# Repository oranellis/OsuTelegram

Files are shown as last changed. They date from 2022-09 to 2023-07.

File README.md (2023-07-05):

# OsuTelegram
Introducing a contact based keypad designed to make tapping in time on two key rhythm games (osu!) faster, tigher timed and requiring less force leading to faster streaming, better accuracy and less fatigue when playing. The keypad requires an RP2040-Zero Microcontroller (found cheaply online), 2 5mmx3mm magnets, 2 49E Linear Hall effect sensors, 4 bearings (8x4x3mm), two keyswitch springs (choose force based on preference however a lighter spring e.g. 35-40g is recommended for less fatigue), and access to a 3D printer.

To construct the keypad, print the .stl files in the `mdl` folder. Glue the hall effect sensors in the gaps on the base with the rounded section facing into the slot. Wire up the hall sensors to GND, 5V and the two analogue inputs shown on the wiring diagram. Slot the bearings onto the keyswitch ends and push fit the magnets into the holes on the bottom. Glue a strip of 1mm thick foam over the hall sensor pad. Slot the keyswitch and bearings into the base and slot the springs into the base and switches. Glue the top peice onto the base, encasing the bearings and switches. Plug the RP2040-Zero into a computer running linux and run the flashing script, alternatively compile the project and flash the RP2040-Zero yourself if you are able.

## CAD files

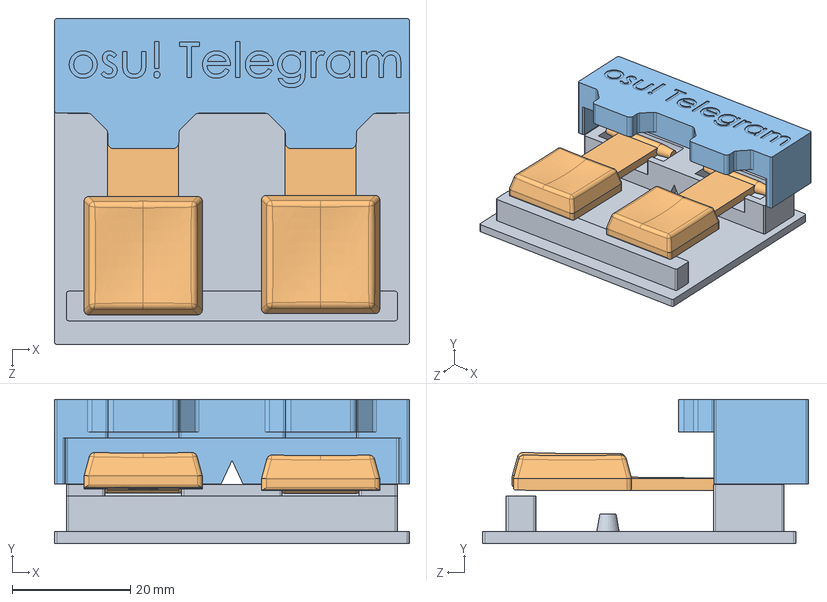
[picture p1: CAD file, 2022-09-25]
mdl/keypad assembly.SLDASM
60.0 x 24.3 x 55.1 mm
case bottom
key x 2
case top

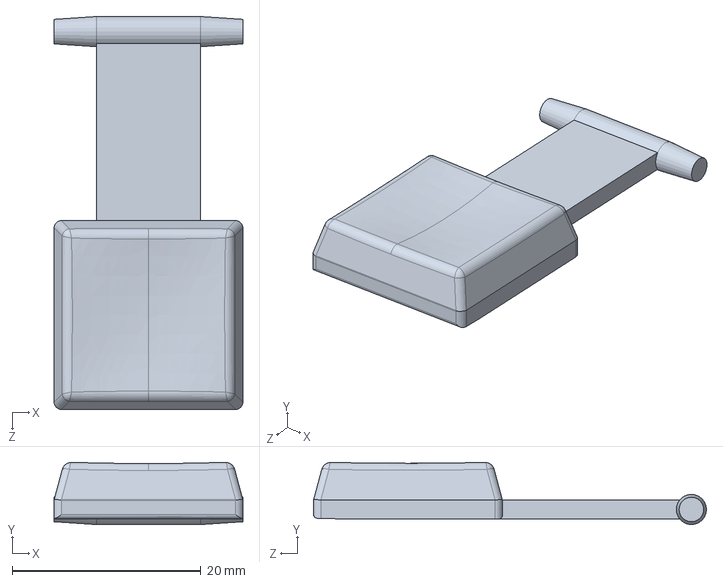
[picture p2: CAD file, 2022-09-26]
mdl/key.SLDPRT
20.0 x 6.58 x 41.6 mm

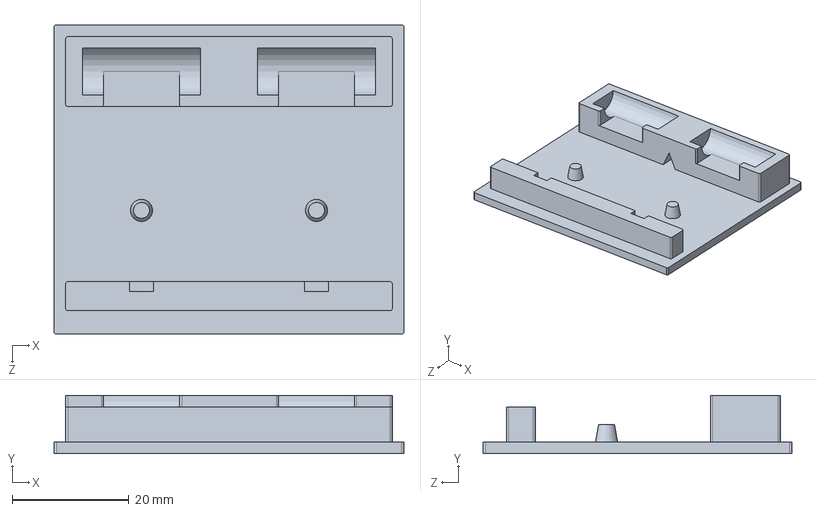
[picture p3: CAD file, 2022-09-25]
mdl/case bottom.SLDPRT
60.0 x 10.0 x 53.0 mm

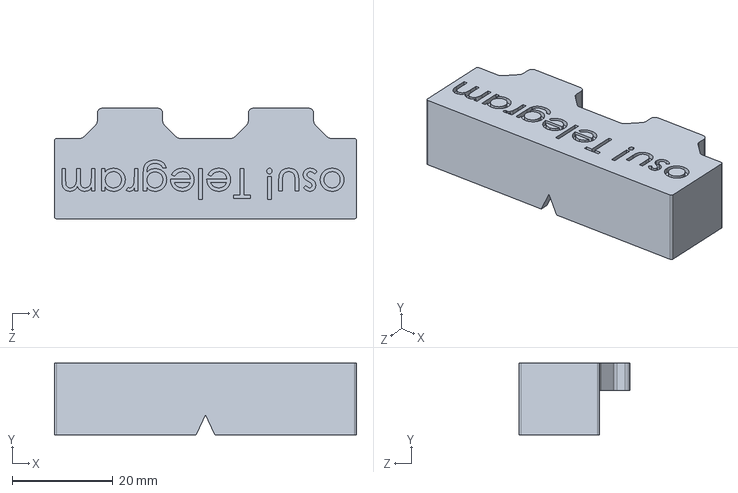
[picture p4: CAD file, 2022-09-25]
mdl/case top.SLDPRT
60.0 x 14.3 x 22.0 mm

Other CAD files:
mdl/case bottom.STL
mdl/case top.STL

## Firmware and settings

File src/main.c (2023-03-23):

/* 
 * The MIT License (MIT)
 *
 * Copyright (c) 2019 Ha Thach (tinyusb.org)
 *
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
 */
#include <stdlib.h>
#include <stdio.h>
#include <string.h>

#include "bsp/board.h"
#include "tusb.h"
#include "hardware/adc.h"
#include "hardware/gpio.h"
#include "hardware/sync.h"
#include "hardware/structs/ioqspi.h"
#include "hardware/structs/sio.h"

#include "usb_descriptors.h"
#include "thing.h"

#define ADC0 26
#define ADC1 27

//--------------------------------------------------------------------+
// MACRO CONSTANT TYPEDEF PROTYPES
//--------------------------------------------------------------------+

/* Blink pattern
 * - 250 ms  : device not mounted
 * - 1000 ms : device mounted
 * - 2500 ms : device is suspended
 */


enum  {
  BLINK_NOT_MOUNTED = 250,
  BLINK_MOUNTED = 1000,
  BLINK_SUSPENDED = 2500,
};

bool z_hold = false;
bool x_hold = false;
int X_TRIG = 1960;
int X_RELEASE = 2110;
int Z_TRIG = 2230;
int Z_RELEASE = 2430;
uint16_t Z_UNPRESSED = 0;
uint16_t X_UNPRESSED = 0;


static uint32_t blink_interval_ms = BLINK_NOT_MOUNTED;

void led_blinking_task(void);
void hid_task(void);

/*------------- MAIN -------------*/
int main(void)
{
    board_init();

    adc_init();
    adc_gpio_init(ADC0);
    adc_gpio_init(ADC1);
    tusb_init();

    sleep_ms(500);
    adc_select_input(0);
    uint16_t Z_UNPRESSED = adc_read();
    adc_select_input(1);
    uint16_t X_UNPRESSED = adc_read();
    board_led_write(true);
    while (1)
    {
    tud_task(); // tinyusb device task
    // led_blinking_task();
    hid_task();
}

return 0;
}

//--------------------------------------------------------------------+
// Device callbacks
//--------------------------------------------------------------------+

// Invoked when device is mounted
void tud_mount_cb(void)
{
  blink_interval_ms = BLINK_MOUNTED;
}

// Invoked when device is unmounted
void tud_umount_cb(void)
{
  blink_interval_ms = BLINK_NOT_MOUNTED;
}

// Invoked when usb bus is suspended
// remote_wakeup_en : if host allow us  to perform remote wakeup
// Within 7ms, device must draw an average of current less than 2.5 mA from bus
void tud_suspend_cb(bool remote_wakeup_en)
{
  (void) remote_wakeup_en;
  blink_interval_ms = BLINK_SUSPENDED;
}

// Invoked when usb bus is resumed
void tud_resume_cb(void)
{
  blink_interval_ms = BLINK_MOUNTED;
}

//--------------------------------------------------------------------+
// USB HID
//--------------------------------------------------------------------+

static void send_hid_report(uint8_t report_id, bool x_hold, bool z_hold)
{
  // skip if hid is not ready yet
  if ( !tud_hid_ready() ) return;

  switch(report_id)
  {
    case REPORT_ID_KEYBOARD:
    {
      // use to avoid send multiple consecutive zero report for keyboard
      static bool has_keyboard_key = false;

      if ( x_hold || z_hold )
      {
        uint8_t keycode[6] = { 0 };
        keycode[0] = HID_KEY_X * x_hold;
        keycode[1] = HID_KEY_Z * z_hold;

        tud_hid_keyboard_report(REPORT_ID_KEYBOARD, 0, keycode);
        has_keyboard_key = true;
      }else
      {
        // send empty key report if previously has key pressed
        if (has_keyboard_key) tud_hid_keyboard_report(REPORT_ID_KEYBOARD, 0, NULL);
        has_keyboard_key = false;
      }
    }
    break;

    case REPORT_ID_MOUSE:
    {
      int8_t const delta = 0;

      // no button, right + down, no scroll, no pan
      tud_hid_mouse_report(REPORT_ID_MOUSE, 0x00, delta, delta, 0, 0);
    }
    break;

    case REPORT_ID_CONSUMER_CONTROL:
    {
      // use to avoid send multiple consecutive zero report
      static bool has_consumer_key = false;

      if ( false )
      {
        // volume down
        uint16_t volume_down = HID_USAGE_CONSUMER_VOLUME_DECREMENT;
        tud_hid_report(REPORT_ID_CONSUMER_CONTROL, &volume_down, 2);
        has_consumer_key = true;
      }else
      {
        // send empty key report (release key) if previously has key pressed
        uint16_t empty_key = 0;
        if (has_consumer_key) tud_hid_report(REPORT_ID_CONSUMER_CONTROL, &empty_key, 2);
        has_consumer_key = false;
      }
    }
    break;

    case REPORT_ID_GAMEPAD:
    {
      // use to avoid send multiple consecutive zero report for keyboard
      static bool has_gamepad_key = false;

      hid_gamepad_report_t report =
      {
        .x   = 0, .y = 0, .z = 0, .rz = 0, .rx = 0, .ry = 0,
        .hat = 0, .buttons = 0
      };

      if ( false )
      {
        report.hat = GAMEPAD_HAT_UP;
        report.buttons = GAMEPAD_BUTTON_A;
        tud_hid_report(REPORT_ID_GAMEPAD, &report, sizeof(report));

        has_gamepad_key = true;
      }else
      {
        report.hat = GAMEPAD_HAT_CENTERED;
        report.buttons = 0;
        if (has_gamepad_key) tud_hid_report(REPORT_ID_GAMEPAD, &report, sizeof(report));
        has_gamepad_key = false;
      }
    }
    break;

    default: break;
  }
}

// Every 10ms, we will sent 1 report for each HID profile (keyboard, mouse etc ..)
// tud_hid_report_complete_cb() is used to send the next report after previous one is complete
void hid_task(void)
{
  // Poll every 10ms
  const uint32_t interval_ms = 1;
  static uint32_t start_ms = 0;

  if ( board_millis() - start_ms < interval_ms) return; // not enough time
  start_ms += interval_ms;

    adc_select_input(0);
    uint16_t result_z = adc_read();
    adc_select_input(1);
    uint16_t result_x = adc_read();

    if (get_bootsel_buttony()) {
        // X_TRIG = X_UNPRESSED-(0.8*(X_UNPRESSED-result_x));
        // Z_TRIG = Z_UNPRESSED-(0.8*(Z_UNPRESSED-result_z));
        // X_RELEASE = X_UNPRESSED-(0.6*(X_UNPRESSED-result_x));
        // Z_RELEASE = Z_UNPRESSED-(0.6*(Z_UNPRESSED-result_z));
        X_TRIG = result_x*1.1;
        Z_TRIG = result_z*1.1;
        X_RELEASE = result_x*1.2;
        Z_RELEASE = result_z*1.2;
    }

    if (!z_hold && result_z < Z_TRIG) {
        z_hold = true;
    }
    if (z_hold && result_z > Z_RELEASE) {
        z_hold = false;
    }

    if (!x_hold && result_x < X_TRIG) {
        x_hold = true;
    }
    if (x_hold && result_x > X_RELEASE) {
        x_hold = false;
    }

  // Remote wakeup
  if ( tud_suspended() && (x_hold || z_hold) )
  {
    // Wake up host if we are in suspend mode
    // and REMOTE_WAKEUP feature is enabled by host
    tud_remote_wakeup();
  }else
  {
    // Send the 1st of report chain, the rest will be sent by tud_hid_report_complete_cb()
    send_hid_report(REPORT_ID_KEYBOARD, x_hold, z_hold);
  }
}

// Invoked when sent REPORT successfully to host
// Application can use this to send the next report
// Note: For composite reports, report[0] is report ID
void tud_hid_report_complete_cb(uint8_t instance, uint8_t const* report, uint8_t len)
{
  (void) instance;
  (void) len;

  uint8_t next_report_id = report[0] + 1;

  if (next_report_id < REPORT_ID_COUNT)
  {
    send_hid_report(next_report_id, x_hold, z_hold);
  }
}

// Invoked when received GET_REPORT control request
// Application must fill buffer report's content and return its length.
// Return zero will cause the stack to STALL request
uint16_t tud_hid_get_report_cb(uint8_t instance, uint8_t report_id, hid_report_type_t report_type, uint8_t* buffer, uint16_t reqlen)
{
  // TODO not Implemented
  (void) instance;
  (void) report_id;
  (void) report_type;
  (void) buffer;
  (void) reqlen;

  return 0;
}

// Invoked when received SET_REPORT control request or
// received data on OUT endpoint ( Report ID = 0, Type = 0 )
void tud_hid_set_report_cb(uint8_t instance, uint8_t report_id, hid_report_type_t report_type, uint8_t const* buffer, uint16_t bufsize)
{
  (void) instance;

  if (report_type == HID_REPORT_TYPE_OUTPUT)
  {
    // Set keyboard LED e.g Capslock, Numlock etc...
    if (report_id == REPORT_ID_KEYBOARD)
    {
      // bufsize should be (at least) 1
      if ( bufsize < 1 ) return;

    }
  }
}

//--------------------------------------------------------------------+
// BLINKING TASK
//--------------------------------------------------------------------+
void led_blinking_task(void)
{
  static uint32_t start_ms = 0;
  static bool led_state = false;

  // blink is disabled
  if (!blink_interval_ms) return;

  // Blink every interval ms
  if ( board_millis() - start_ms < blink_interval_ms) return; // not enough time
  start_ms += blink_interval_ms;

  board_led_write(led_state);
  led_state = 1 - led_state; // toggle
}

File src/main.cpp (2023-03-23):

//  ___           _____    _
// / _ \ ___ _   |_   _|__| | ___  __ _ _ __ __ _ _ __ ___
//| | | / __| | | || |/ _ \ |/ _ \/ _` | '__/ _` | '_ ` _ \
//| |_| \__ \ |_| || |  __/ |  __/ (_| | | | (_| | | | | | |
// \___/|___/\__,_||_|\___|_|\___|\__, |_|  \__,_|_| |_| |_|
//

#include <stdio.h>

#include "pico/stdlib.h"
#include "pico/stdio.h"
#include "hardware/gpio.h"
#include "hardware/adc.h"

#define LED_PIN 25
#define ADC0 26
#define ADC1 27

int main() {
    stdio_init_all();
    gpio_init(LED_PIN);
    gpio_set_dir(LED_PIN, GPIO_OUT);
    gpio_put(LED_PIN,true);

    adc_init();
    adc_gpio_init(ADC0);
    adc_select_input(0);

    uint16_t min_hall = 65535;
    uint16_t max_hall = 0;
    for (int i = 0; i<100000; i++) {
        uint16_t result = adc_read();
        if (result > max_hall) {
            max_hall = result;
        }
        if (result < min_hall) {
            min_hall = result;
        }
        sleep_us(100);
    }
    gpio_put(LED_PIN,false);

    printf("vals between %i and %i", min_hall, max_hall);
    sleep_ms(5000);
    while (true) {
        uint16_t result = adc_read();
        sleep_ms(33);
        printf("\nresult: %i",result);
    }
}

int websocket() {
    int port;
    int
}

// int main() {
//     stdio_init_all();
//     printf("ADC Example, measuring GPIO26\n");

//     adc_init();

//     // Make sure GPIO is high-impedance, no pullups etc
//     adc_gpio_init(26);
//     // Select ADC input 0 (GPIO26)
//     adc_select_input(0);

//     while (1) {
//         // 12-bit conversion, assume max value == ADC_VREF == 3.3 V
//         const float conversion_factor = 3.3f / (1 << 12);
//         uint16_t result = adc_read();
//         printf("Raw value: 0x%03x, voltage: %f V\n", result, result * conversion_factor);
//         sleep_ms(1);
//     }
// }

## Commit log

2022-09-22 Readme updated for contact switch version
2022-09-22 Initial hall_effect based keypad commit
    [file.stl]
2022-09-22 Added contact keypad models and restructured folders
    [case bottom.SLDPRT, case bottom.STL, case top.SLDPRT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]
2022-09-23 Test code for hall effect sensors
2022-09-25 Created model for hall effect keypad
    [case bottom.SLDPRT, case bottom.STL, case top.SLDPRT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]
2022-09-26 Updated key model for better performance and tolerances
    [file.stl, key.SLDPRT]
2022-09-26 Example LED implementation TODO HID keyboard implmementation
2022-09-26 bad implementation of hall sensor but it works
2023-07-05 Removed legacy contact keypad
    [case bottom.SLDPRT, case bottom.STL, case top.SLDPRT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]
